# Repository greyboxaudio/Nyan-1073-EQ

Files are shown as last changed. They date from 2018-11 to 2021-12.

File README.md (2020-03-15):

# NYAN 1073 
(*Not Yet Another Neve)

Inspired by the Poor Man's Pultec (https://groupdiy.com/index.php?topic=43859.0) this is my take on the classic 1073 Equalizer.
The main goal of this project is to give people an affordable option for building this EQ. This is achieved by replacing all inductors with gyrators aka 'simulated inductors'.
I also want to help people gain a better understanding of the original circuit.

You can find the corresponding GroupDIY topic over here: https://groupdiy.com/index.php?topic=70096.0
as well as a topic on gearslutz: https://www.gearslutz.com/board/geekslutz-forum/1235388-diy-poor-mans-1073-eq.html

## Random notes

*	I assume that you already have a suitable power supply for this circuit. As I'm mostly playing around with Eurorack stuff, I've been using this design for a linear regulated +/-12v PSU: http://electro-music.com/forum/post-389344.html
* I’ve indicated which parts of the circuit correspond to the original 1073
*	I won’t link to any original 1073 schematics, as they are easy enough to find if you search for “1073 1084 user manual issue5”
* The BA211 board caused me quite a headache, until I finally figured out, that the original circuit only uses the 200mH tap of the T1280 inductor.
* The two amplifiers on the BA284 board, that are used for the EQ circuits, function like basic inverting Op-Amps (see https://repforums.prosoundweb.com/index.php/topic,34458.html#msg509550)
* TL07x opamps will get the job done, but I got better results (lower noise at line level), by using NE5532 Opamps for the amplifiers, as well as for the gyrator circuits.
* The presence band shows lower maximum gain at higher frequencies. This effect is a characteristic of the original circuit (see http://www.uaudio.com/webzine/2006/may/text/content2.html)
* Feel free to play around with the circuit using the LTSpice .asc schematic:) LTSpice is freely available from Analog Devices http://www.analog.com/en/design-center/design-tools-and-calculators/ltspice-simulator.html

As there are no potentiometers in LTSpice, I used serial resistors instead. So if you change the value on one side (turning the imaginary resistor) you need to change the other resistor accordingly.

## References

*	The following article from Rod Elliott has been very helpful in understanding and implementing gyrators http://sound-au.com/articles/gyrator-filters.htm
*	The inductance and resistance values for the different inductors have been taken from here http://www.sowter.co.uk/eqinductors.php
*	I’ve used the Waves Scheps 73 plugin as my main reference for the frequency response https://www.waves.com/plugins/scheps-73
*	DDMF’s Plugindoctor has been a great tool for measuring and referencing my circuit with the plugin https://ddmf.eu/plugindoctor/
* Special thanks goes out to gearslutz user Cabirio, who helped a lot in optimizing the circuit 

## Disclaimer
Neve is a registered trademark of AMS/Neve Inc.
This project is not affiliated, endorsed or supported by AMS/Neve in any manner.

## License

This work is licensed under the Creative Commons Attribution-ShareAlike 4.0 International License.
To view a copy of this license, visit http://creativecommons.org/licenses/by-sa/4.0/ or send a letter to
Creative Commons, PO Box 1866, Mountain View, CA 94042, USA.

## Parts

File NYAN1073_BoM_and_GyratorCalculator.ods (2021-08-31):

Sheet: Bill_of_Materials
Component | Value | Quantity | Revision 8 This work is licensed under the Creative Commons Attribution-ShareAlike 4.0 International License. To view a copy of this license, visit http://creativecommons.org/licenses/by-sa/4.0/ or send a letter to Creative Commons, PO Box 1866, Mountain View, CA 94042, USA.
Capacitor (ceramic) | 0,1uF | 10
Capacitor (electrolytic) | 100uF | 2
Capacitor (electrolytic) | 22uF | 1
Capacitor (film) | 100nF | 9
Capacitor (film) | 10nF | 10
Capacitor (film) | 150pF | 1
Capacitor (film) | 15nF | 3
Capacitor (film) | 1uF | 2
Capacitor (film) | 2200pF | 2
Capacitor (film) | 220nF | 2
Capacitor (film) | 220pF | 1
Capacitor (film) | 22nF | 5
Capacitor (film) | 4700pF | 1
Capacitor (film) | 470nF | 2
Capacitor (film) | 470pF | 1
Capacitor (film) | 47nF | 3
IC | NE5532 | 4
IC | LM4562 | 1
Potentiometer | 10k linear | 1
Potentiometer | 50k linear | 1
Potentiometer | 10k linear | 1
Resistor | 300 | 1
Resistor | 330 | 1
Resistor | 360 | 1
Resistor | 470 | 1
Resistor | 560 | 1
Resistor | 620 | 2
Resistor | 820 | 2
Resistor | 1.000 | 1
Resistor | 1.200 | 1
Resistor | 18.000 | 1
Resistor | 3.300 | 1
Resistor | 3.900 | 1
Resistor | 4.700 | 1
Resistor | 5.100 | 2
Resistor | 6.800 | 4
Resistor | 8.200 | 1
Resistor | 10.000 | 2
Resistor | 12.000 | 2
Resistor | 16.000 | 1
Resistor | 39.000 | 1
Resistor | 33.000 | 1
Resistor | 56.000 | 1
Resistor | 620.000 | 1
Resistor | 820.000 | 1
Resistor | 1.000.000 | 1
Resistor | 120.000 | 1
Resistor | 180.000 | 1
Resistor | 430.000 | 1
Resistor | 240.000 | 1
Resistor | 4.700.000 | 19
Rotary Switch | 12 Pos. / 3 Pole | 1
Rotary Switch | 12 Pos. / 3 Pole | 1
Rotary Switch | 12 Pos. / 2 Pole | 1
Switch | 3 Way / 2 pole | 1
Potentiometer (Trimmer) | 5k | 6

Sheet: Gyrator_Calculator
Original Inductor | Inductance in H | Resistance in Ohms | R1 in Ohms | C1 in nF | ideal R14 | R2 | add. R2 | Inductance in H | margin of error
T1295 | 10,000 | 1.000 | 1.000 | 10 | 1.000.000 | 1.000.000 |  | 10,000 | 0,000%
 | 7,000 | 800 | 820 | 10 | 853.659 | 820.000 | 33.000 | 6,995 | 0,077%
 | 3,000 | 490 | 470 | 10 | 638.298 | 620.000 | 18.000 | 2,999 | 0,047%
 | 1,300 | 310 | 300 | 10 | 433.333 | 430.000 | 3.300 | 1,300 | 0,008%
T1530 | 2,000 | 85 | 820 | 10 | 243.902 | 240.000 | 3.900 | 2,000 | 0,001%
 | 1,100 | 59 | 560 | 10 | 196.429 | 180.000 | 16.000 | 1,098 | 0,218%
 | 0,450 | 35 | 360 | 10 | 125.000 | 120.000 | 5.100 | 0,450 | -0,080%
T1280 | 0,200 | 32 | 330 | 10 | 60.606 | 56.000 | 4.700 | 0,200 | -0,155%
 | 0,160 | 28 | 27 | 100 | 59.259 | 56.000 | 3.200 | 0,160 | 0,100%
 | 0,100 | 22 | 22 | 100 | 45.455 | 43.000 | 2.400 | 0,100 | 0,120%
 | 0,080 | 20 | 20 | 100 | 40.000 | 39.000 | 1.000 | 0,080 | 0,000%
 | 0,050 | 16 | 16 | 100 | 31.250 | 30.000 | 1.200 | 0,050 | 0,160%
The blue marked inductor taps are not used in the original 1073 circuit

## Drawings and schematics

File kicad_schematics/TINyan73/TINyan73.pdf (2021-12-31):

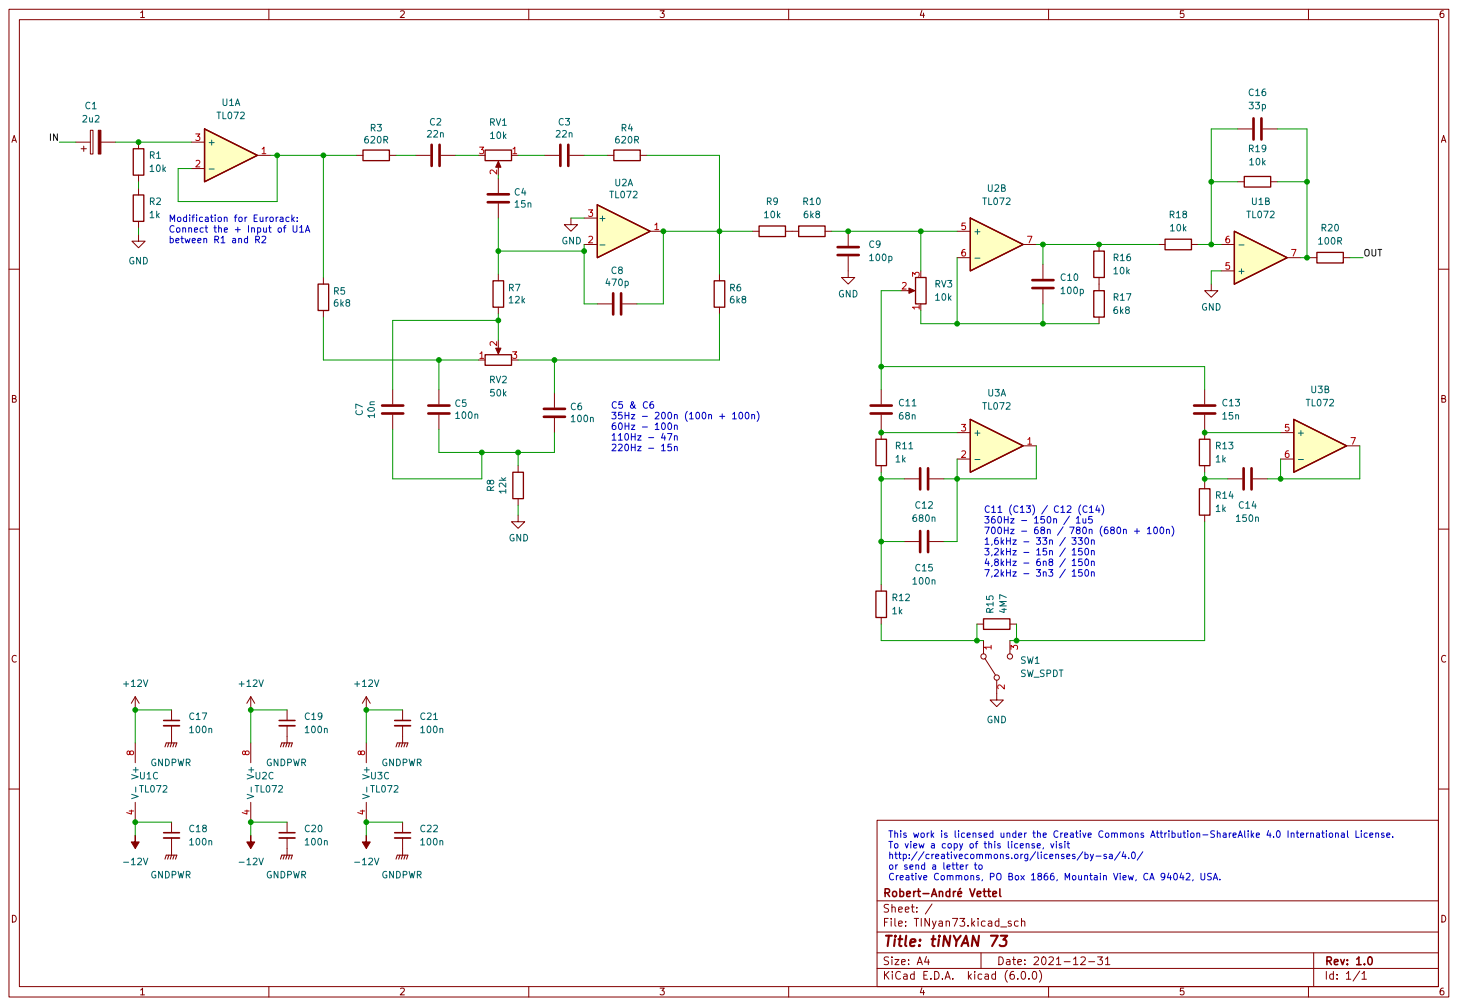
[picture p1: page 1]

7,2kHz - 3n3 / 150n Modification for Eurorack: Connect the + Input of U1A

http://creativecommons.org/licenses/by-sa/4.0/ or send a letter to Creative Commons, PO Box 1866, Mountain View, CA 94042, USA. C11 (C13) / C12 (C14) 360Hz - 150n / 1u5

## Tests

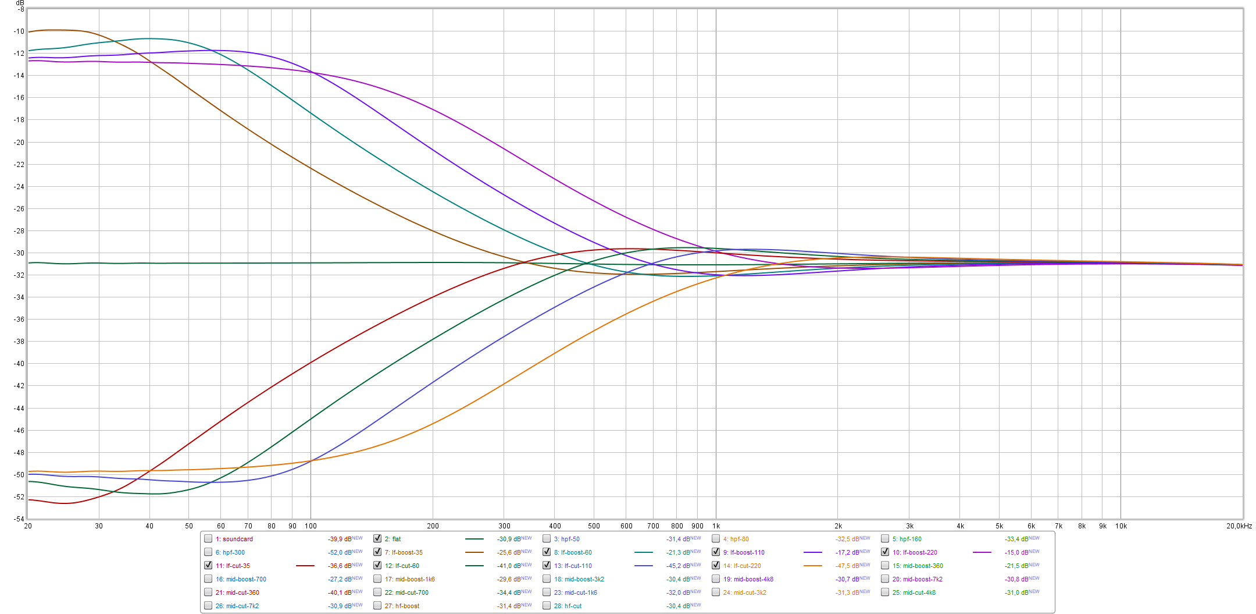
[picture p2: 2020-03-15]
measurements/nyan1073_lf.png

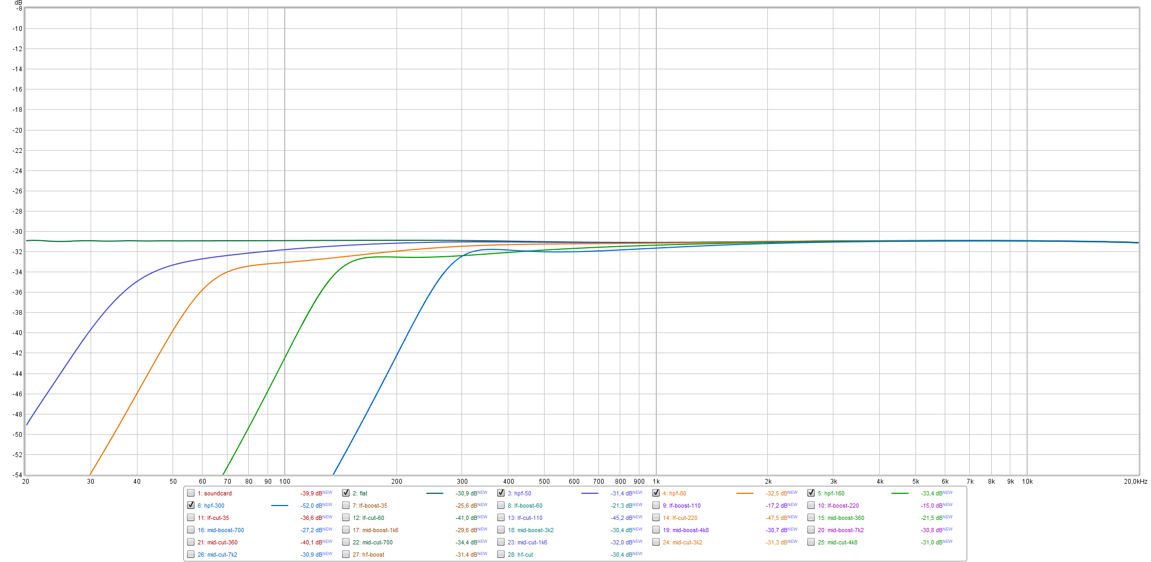
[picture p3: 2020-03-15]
measurements/nyan1073_hpf.png

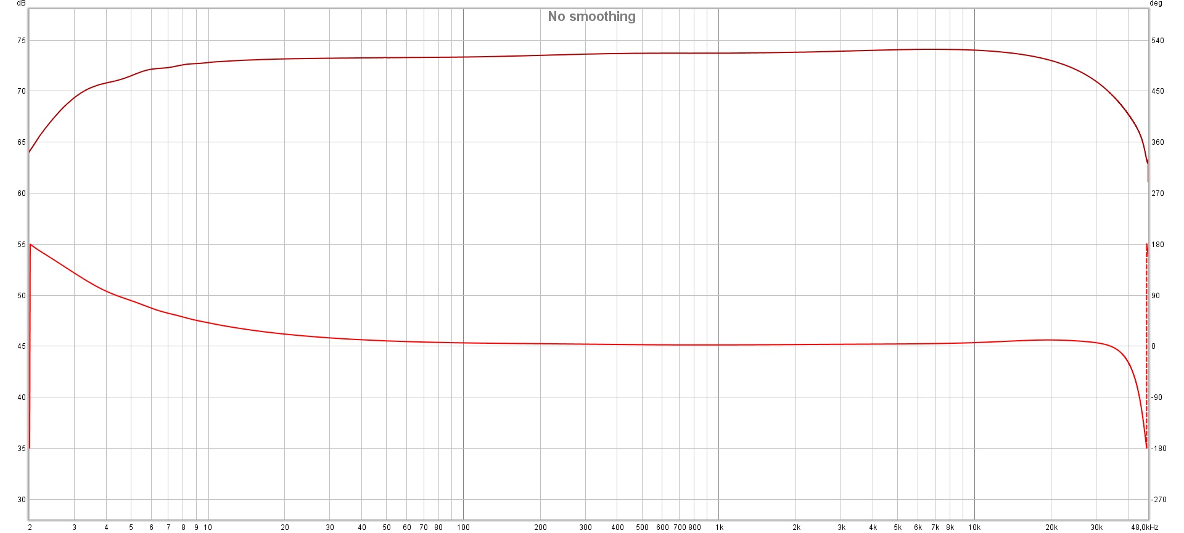
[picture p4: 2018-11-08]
measurements/cheaps73_spl_phase.jpg

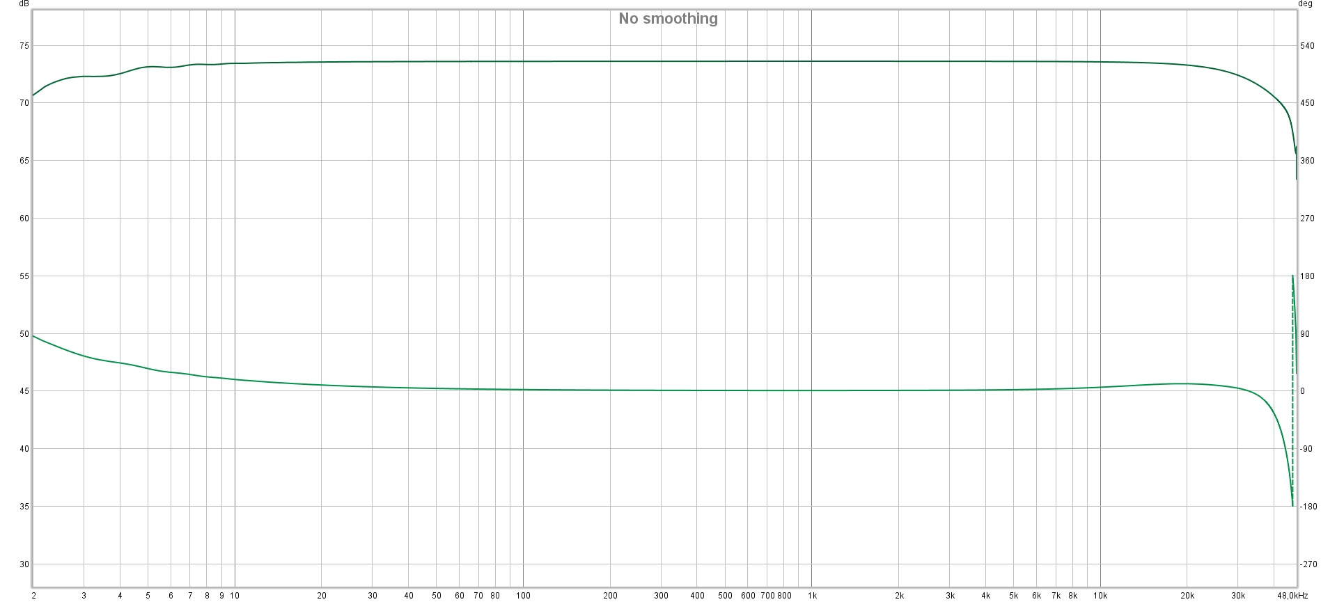
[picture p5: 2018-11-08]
measurements/cheaps73_spl_phase_reference.jpg

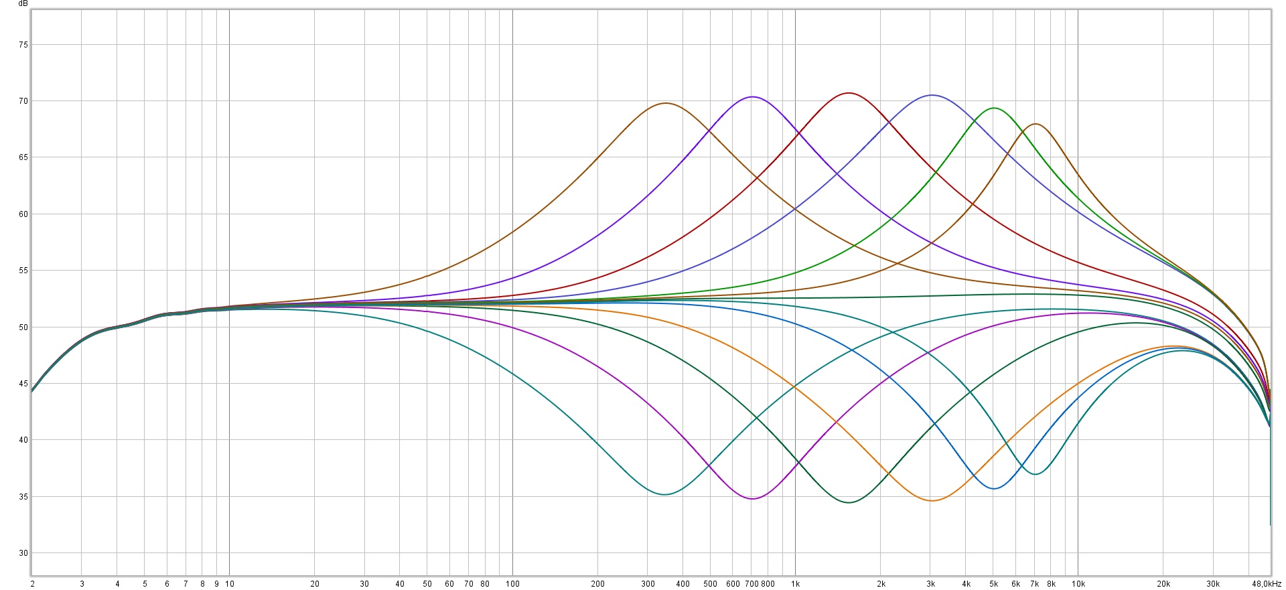
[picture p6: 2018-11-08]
measurements/cheaps73_Mid.jpg

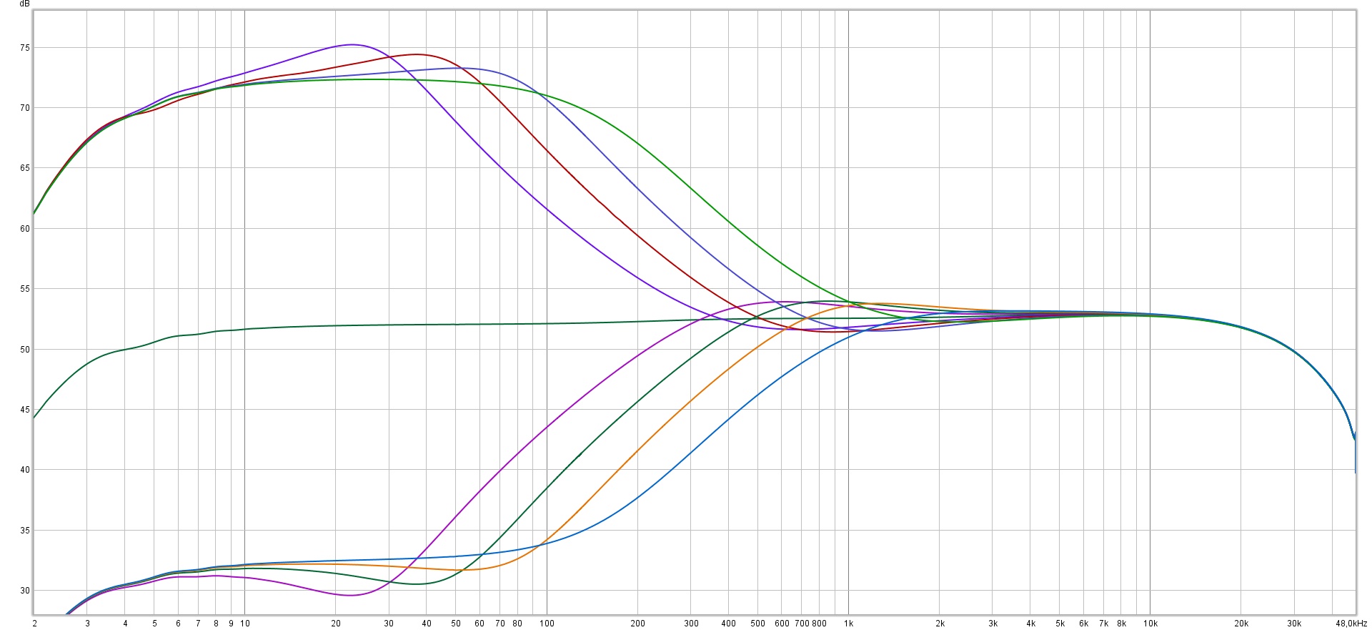
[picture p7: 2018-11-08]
measurements/cheaps73_Low.jpg

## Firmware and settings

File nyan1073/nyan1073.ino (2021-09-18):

#include <Wire.h>
#include <Adafruit_GFX.h>
#include <Adafruit_SSD1306.h>

#define SCREEN_WIDTH 128 // OLED display width, in pixels
#define SCREEN_HEIGHT 64 // OLED display height, in pixels

// Declaration for an SSD1306 display connected to I2C (SDA, SCL pins)
#define OLED_RESET     4 // Reset pin # (or -1 if sharing Arduino reset pin)
Adafruit_SSD1306 display(SCREEN_WIDTH, SCREEN_HEIGHT, &Wire, OLED_RESET);

int analogPin1 = A0;  //Low Freq dB
int analogPin2 = A1;  //Mid Freq dB
int analogPin3 = A2;  //High Freq dB
int analogPin4 = A3;  //HPF Freq Hz
int analogPin5 = A6;  //Low Freq Hz
int analogPin6 = A7;  //Mid Freq Hz

//individually calibrated center values for all potentiometers
int offset1 = 523; //High Frequency Center
int offset2 = 506; //Mid Frequency Center
int offset3 = 498; //Low Frequency Center

//Zero display range
int zeroDisplay = 2;

const int numReadings = 7;
int readIndex = 0;                 // the index of the current reading
int readings_A0[numReadings];      // the readings from the analog input
int total_A0 = 0;                  // the running total
int average_A0 = 0;                // the average
int readings_A1[numReadings];      // the readings from the analog input
int total_A1 = 0;                  // the running total
int average_A1 = 0;                // the average
int readings_A2[numReadings];      // the readings from the analog input
int total_A2 = 0;                  // the running total
int average_A2 = 0;                // the average

int frequencyA = 0; // HPF Frequency Select
int frequencyB = 0;
int frequencyC = 0;

float gainMod1Pos = 0;
float gainMod1Neg = 0;
float gainMod2Pos = 0;
float gainMod2Neg = 0;
float gainMod3Pos = 0;
float gainMod3Neg = 0;

float out1 = 0;
float out2 = 0;
float out3 = 0;

void setup() {
  Serial.begin(9600);           //  setup serial

   // initialize all the readings to 0:
  for (int thisReading = 0; thisReading < numReadings; thisReading++) {
    readings_A0[thisReading] = 0;
    readings_A1[thisReading] = 0;
    readings_A2[thisReading] = 0;
  }

  // SSD1306_SWITCHCAPVCC = generate display voltage from 3.3V internally
  if(!display.begin(SSD1306_SWITCHCAPVCC, 0x3C)) { // Address 0x3C for 128x64
    Serial.println(F("SSD1306 allocation failed"));
    for(;;); // Don't proceed, loop forever
  }

  // calculate individual gain modifiers
  gainMod1Pos = 1023 - offset1;
  gainMod1Pos = 16 / gainMod1Pos;
  gainMod1Neg = offset1;
  gainMod1Neg = 16 / gainMod1Neg;

  gainMod2Pos = 1023 - offset2;
  gainMod2Pos = 18 / gainMod2Pos;
  gainMod2Neg = offset2;
  gainMod2Neg = 18 / gainMod2Neg;

  gainMod3Pos = 1023 - offset3;
  gainMod3Pos = 16 / gainMod3Pos;
  gainMod3Neg = offset3;
  gainMod3Neg = 16 / gainMod3Neg;
  
  // Show initial display buffer contents on the screen --
  // the library initializes this with an Adafruit splash screen.
  display.clearDisplay();

  display.setTextSize(2);
  display.setTextColor(WHITE);
  display.setCursor(0,0);
  display.println();
  display.println(" NYAN 1073");
  display.println("   =^x^=");
  display.display();
  
  delay(2000);
}

void loop() {
  // subtract the last reading:
  total_A0 = total_A0 - readings_A0[readIndex];
  total_A1 = total_A1 - readings_A1[readIndex];
  total_A2 = total_A2 - readings_A2[readIndex];
  // read from the sensor:
  readings_A0[readIndex] = analogRead(analogPin1);
  readings_A1[readIndex] = analogRead(analogPin2);
  readings_A2[readIndex] = analogRead(analogPin3);
  // add the reading to the total:
  total_A0 = total_A0 + readings_A0[readIndex];
  total_A1 = total_A1 + readings_A1[readIndex];
  total_A2 = total_A2 + readings_A2[readIndex];
  // advance to the next position in the array:
  readIndex = readIndex + 1;

  // if we're at the end of the array...
  if (readIndex >= numReadings) {
    // ...wrap around to the beginning:
    readIndex = 0;
  }

  // calculate average read values
  average_A0 = total_A0 / numReadings;
  average_A1 = total_A1 / numReadings;
  average_A2 = total_A2 / numReadings;

  frequencyB = analogRead(analogPin4);

  // serial output for debugging & calibration
  Serial.print(average_A0);
  Serial.print(" ");
  Serial.print(average_A1);
  Serial.print(" ");
  Serial.print(average_A2);
  Serial.print(" // ");
  Serial.print(frequencyA);
  Serial.print(" ");
  Serial.print(frequencyB);
  Serial.print(" ");
  Serial.println(frequencyC);

  display.clearDisplay();
  display.setTextSize(2);
  display.setTextColor(WHITE);
  display.setCursor(0,0);

  display.print("12k:");
  // calculate output3 in dB
   if (average_A2 > offset3 + zeroDisplay){
    out3 = (average_A2 - offset3)*gainMod3Pos;
    display.println(out3);
  }
  else if (average_A2 < offset3 - zeroDisplay){
    out3 = (average_A2 - offset3)*gainMod3Neg;
    display.println(out3);
  }
  else{
    display.println(0.00);
  }


  //display Mid Frequency
    if (frequencyC < 250){
    display.print("360:");
   }
   if (frequencyC > 250 & frequencyC < 350){
    display.print("700 ");
   }
   if (frequencyC > 350 & frequencyC < 500){
    display.print("1k6 ");
   }
   if (frequencyC > 500 & frequencyC < 700){
    display.print("3k2 ");
   }
   if (frequencyC > 700 & frequencyC < 850){
    display.print("4k8 ");
   }
   if (frequencyC > 850){
    display.print("7k2 ");
   }
  // calculate output2 in dB
  if (average_A1 > offset2 + zeroDisplay){
    out2 = (average_A1 - offset2)*gainMod2Pos;
    display.println(out2);
  }
  else if (average_A1 < offset2 - zeroDisplay){
    out2 = (average_A1 - offset2)*gainMod2Neg;
    display.println(out2);
  }
  else{
    display.println(0.00);
  }

  //display Low Frequency
    if (frequencyB < 300){
    display.print("220:");
   }
   if (frequencyB > 300 & frequencyB < 500){
    display.print("110:");
   }
   if (frequencyB > 500 & frequencyB < 700){
    display.print(" 65:");
   }
   if (frequencyB > 700){
    display.print(" 35:");
   }
  // calculate output1 in dB
  if (average_A0 > offset1 + zeroDisplay){
    out1 = (average_A0 - offset1)*gainMod1Pos;
    display.println(out1);
  }
  else if (average_A0 < offset1 - zeroDisplay){
    out1 = (average_A0 - offset1)*gainMod1Neg;
    display.println(out1);
  }
  else{
    display.println(0.00);
  }

  //display HPF Frequency
    if (frequencyA < 300){
    display.print(" 50:");
   }
   if (frequencyA > 300 & frequencyA < 500){
    display.print(" 80:");
   }
   if (frequencyA > 500 & frequencyA < 700){
    display.print("160:");
   }
   if (frequencyA > 700){
    display.print("300:");
   }
   display.print("HPF");

  display.display();
  
}
  

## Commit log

2018-10-06 Added CC-by-sa-4
    This work is licensed under the Creative Commons Attribution-ShareAlike 4.0 International License. To view a copy of this license, visit http://creativecommons.org/licenses/by-sa/4.0/ or send a lette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
    [poormans1073_BoM_and_GyratorValues.ods]
2018-10-07 Rev02
    Added frequency selectors and on/off switch for the HPF
    [poormans_1073.sch]
2018-10-07 added Readme
    added readme, changed .ods font to Open Sans
    [poormans1073_BoM_and_GyratorValues.ods]
2018-10-07 Schematic Revision 3
    - added capacitor & resistor values for all frequency settings
    - added a direction indicator for all potentiometers
    - updated build notes
    - additional measurement pictures
    [poormans1073_BoM_and_GyratorValues.ods, poormans_1073.sch]
2018-10-07 small fixes
    [poormans_1073.sch]
2018-10-08 LTSpice
    added a full LTSpice simulation of the circuit
2018-10-17 updated schematic
    [poormans73_hpf.sch, poormans73_presence.sch, poormans73_shelf.sch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]
2018-10-21 completed HPF
    added HPF measurements, updated schematics
    [poormans73_hpf.sch, poormans73_presence.sch, poormans73_shelf.sch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]
2018-10-28 finished build
    new project name, special thanks to gearslutz user Cabirio !
    [cheaps73.sch, cheaps73_BoM_and_GyratorCalculator.ods, cheaps73_hp.sch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]
2018-10-28 updated file structure
    [cheaps73.sch, cheaps73_hp.sch, cheaps73_input.sch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]
2018-10-28 removed duplicate schematic
    [cheaps73_output.sch]
2018-10-28 BoM & fixes
    - updated BoM
    - corrected R18 (B211)
    - added R65 (B182C)
    [cheaps73.sch, cheaps73_BoM_and_GyratorCalculator.ods, cheaps73_hp.sch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]
2018-10-28 moved pdf schematic
2018-10-28 removed kicad project
    redundant
2018-11-01 rev 06c
    - added 22uF bypass cap
    - changed gain settings of the output section
    [cheaps73.sch, cheaps73_hp.sch, cheaps73_input.sch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]
2018-11-01 rev:06d
    further tweaking on the output stage, should be final now #fingersCrossed
    [cheaps73.sch, cheaps73_BoM_and_GyratorCalculator.ods, cheaps73_hp.sch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]
2018-11-08 Rev07
    - replaced IC1
    - frequency switching of the presence band has been optimised, to reduce switching noise
    [cheaps73.sch, cheaps73_BoM_and_GyratorCalculator.ods, cheaps73_hp.sch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]
2019-09-02 Update README.md
    updated website of Rod Elliott
2020-01-19 Rev08
    - omitted input/output stages (they were just simple buffers anyway)
    - replaced 2k7 resistor on the B211 board with separate 5k trim pots
    - increased R51 on the B211 board to 5k1
    - increased R4 & R14 on the B205 board to 6k8
    - changed resistor/capacitor scaling in the HPF gyrators
    - moved 5k1 load-resistor from the output section to the HPF circuit
2020-01-24 stuff
    - added first attempt at an Arduino based recall
    - print out template for a half-rack frontpanel
2020-01-26 BoM Rev8
    [cheaps73_BoM_and_GyratorCalculator.ods]
2020-01-27 Schematics Rev08a
    changed naming
    [Nyan1073EQ.sch, Nyan1073EQ_hpf.sch, Nyan1073EQ_presence.sch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]
2020-01-31 power layout sketch
    reference
2020-03-15 arduino sketch v1
2020-03-15 arduino sketch v1.1
    some small tweaks
2020-03-15 nyan1073_measurements
    updated measurements for the current hardware revision
2021-02-01 Nyan Update
    updated naming, improved component indices, optimized layout
    [Nyan1073EQ.sch, Nyan1073EQ_LowHigh.sch, Nyan1073EQ_hpf.sch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]
2021-02-01 Single Sheet Schematic
    [Nyan1073EQ.sch, Nyan1073EQ_LowHigh.sch, Nyan1073EQ_hpf.sch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]
2021-02-01 kicad hates me
    [NYAN1073_BoM_and_GyratorCalculator.ods, Nyan1073_Main.sch]
2021-02-01 Rev09 \o/
    [Nyan1073_Main.sch]
2021-02-01 added TINyan
    [TINyan73.sch]
2021-08-15 update schematics
    [NYAN1073_BoM_and_GyratorCalculator.ods, Nyan1073_Main.sch, TINyan73.kicad_pcb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]
2021-08-31 updated arduino sketch
    added optional "dead zone" parameter
2021-12-31 updated tiNYAN 73
    [TINyan73.kicad_sch, TINyan73.sch]
